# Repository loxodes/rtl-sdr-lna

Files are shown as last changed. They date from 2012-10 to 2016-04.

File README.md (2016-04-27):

**rtl-sdr-lna**

rtl-sdr-lna is a LNA for the ezcap digital TV USB stick (or other USB tuners).
This is intended to improve the sensitivity of it for use as a cheap SDR.

The amplifier is stable, but the matching could probably be improved.

See the following websites for more information on the rtl-sdr:

http://sdr.osmocom.org/trac/wiki/rtl-sdr

http://www.reddit.com/r/rtlsdr

The board is intended to take the place of the RF connector on the ezcap.  

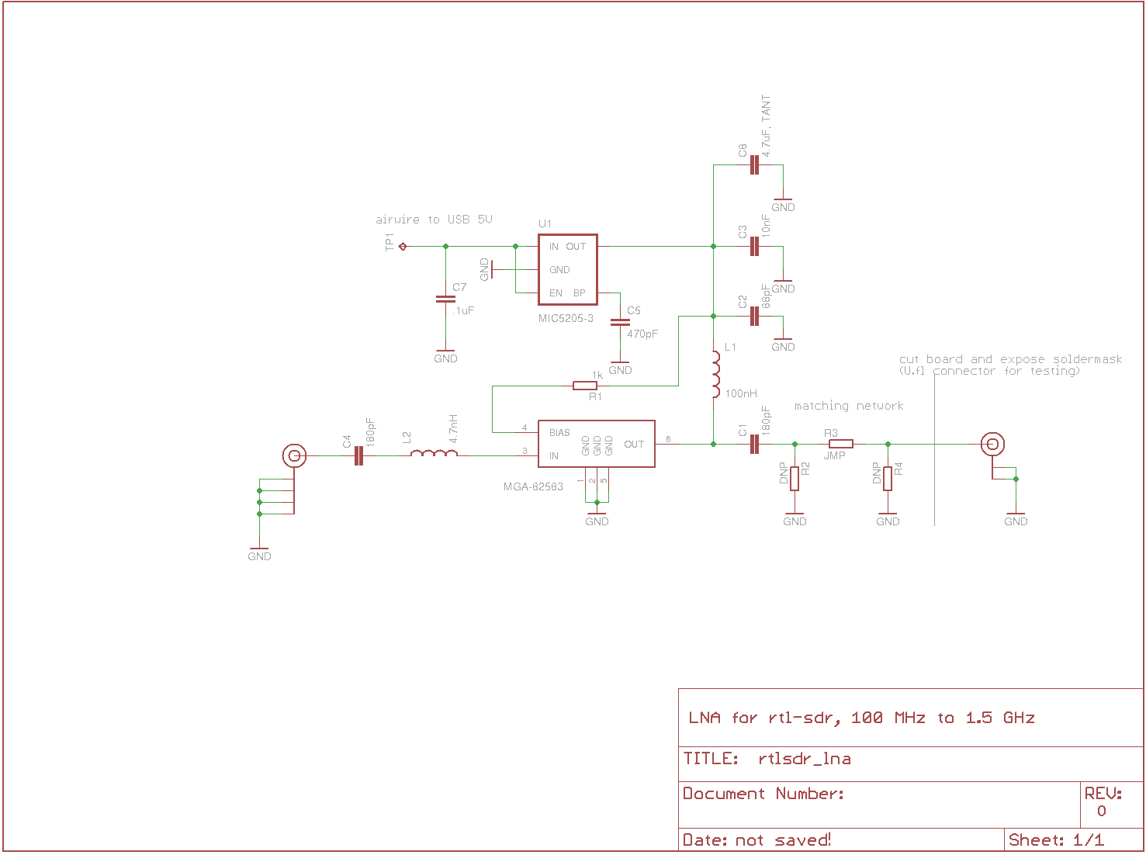
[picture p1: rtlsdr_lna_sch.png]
rtlsdrlna schematic


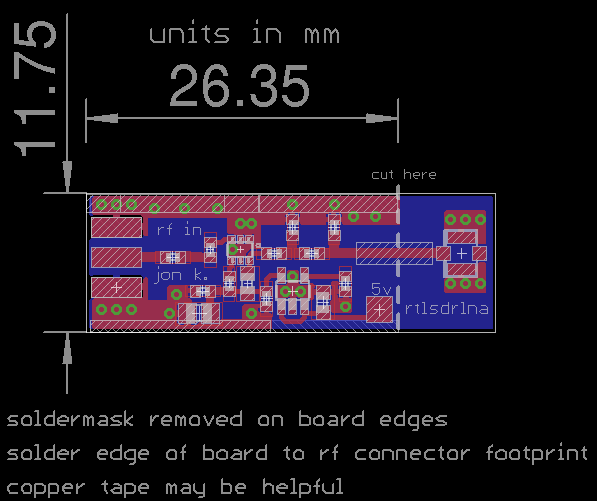
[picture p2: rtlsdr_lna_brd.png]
rtlsdrlna layout


s2p files for simulation are available from Avago and Murata. I'm using ADS for simulation, qucs would be a free open source alternative.

http://www.avagotech.com/pages/en/rf_microwave/amplifiers/low_noise_amplifiers/mga-62563/

http://ds.murata.co.jp/software/simsurfing/en-us/index.html

The PCB can be ordered from OSH Park for $3.15 here: http://oshpark.com/shared_projects/ExVzBewI

All layouts and schematics in this repository are under an MIT license.
Feel free to contact me at jtklein@alaska.edu with suggestions, questions, or complaints.

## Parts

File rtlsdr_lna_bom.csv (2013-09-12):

Qty | Value | Package | Parts
1 | .1uF | C0603 | C7
1 | 100nH | L0603 | L1
1 | 10nF | C0402 | C3
2 | 180pF | C0402 | C1, C4
1 | 1kohm | R0402 | R1
1 | 4.7nH | L0402 | L2
1 | 4.7uF, TANT | C0805 | C6
1 | 470pF | C0402 | C5
1 | 68pF | C0402 | C2
1 | 0 ohm | R0402 | R3
1 | MGA-68563 | SOT363
1 | MIC5205-3 | SOT23-5
1 | SMA_EDGE | SMA-EDGE
1 | U.FL | U.FL

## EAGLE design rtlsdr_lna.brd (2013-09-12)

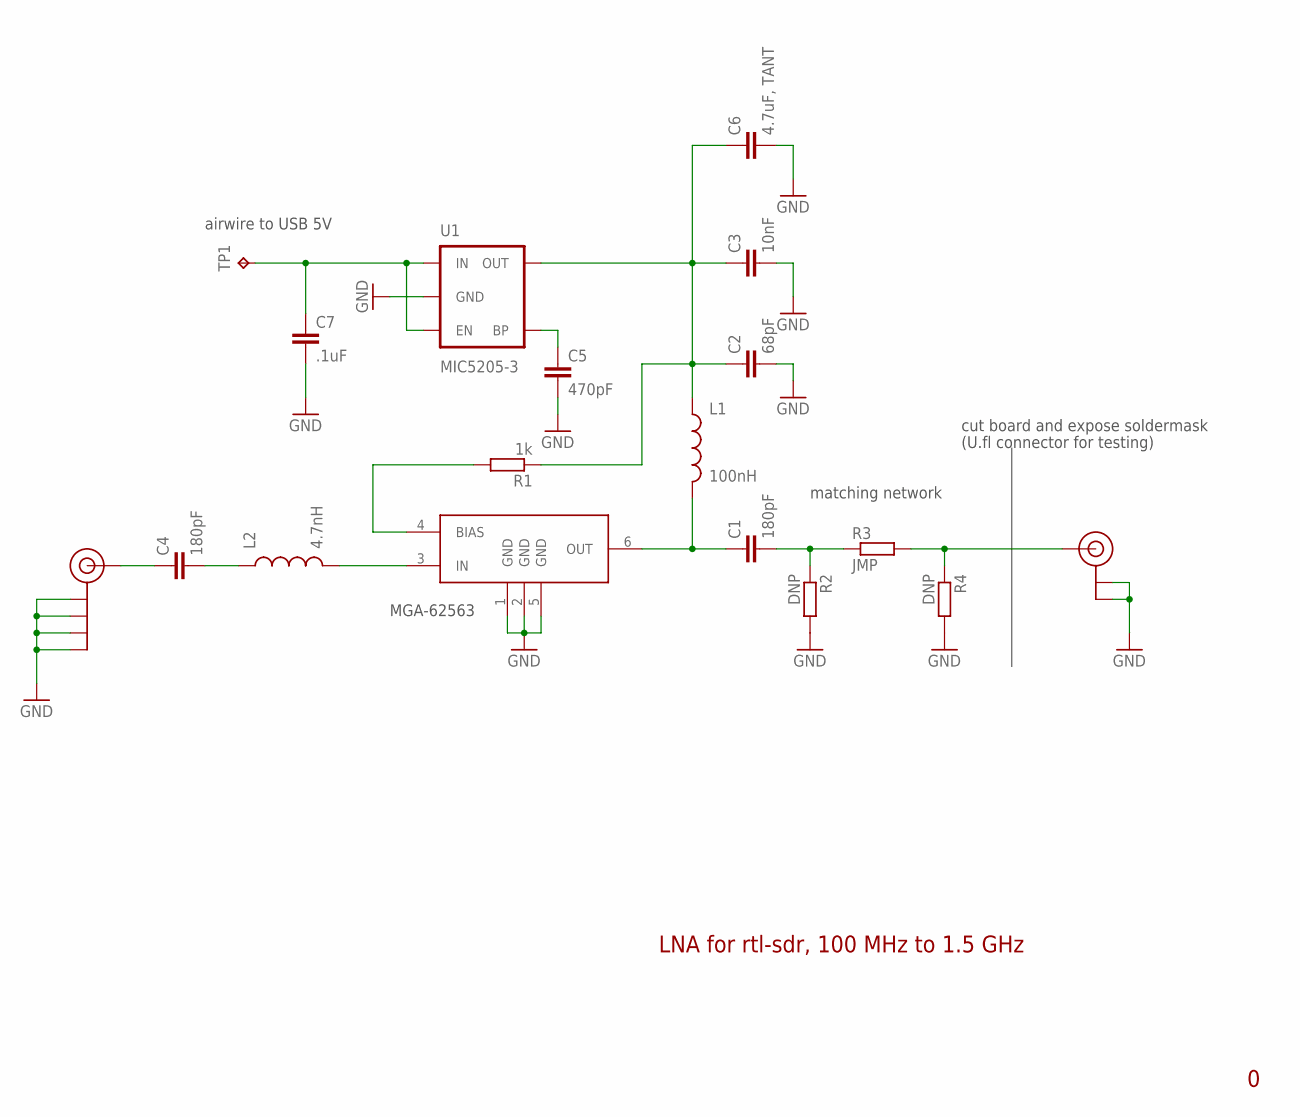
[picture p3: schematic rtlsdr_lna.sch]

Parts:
C1, C4: 180pF; C0402
C2: 68pF; C0402
C3: 10nF; C0402
C5: 470pF; C0402
C6: 4.7uF, TANT; C0805
C7: .1uF; C0603
J$1: SMA_EDGE; SMA-EDGE
L1: 100nH; 0603
L2: 4.7nH; C0402
R1: 1k; R0402
R2, R4: DNP; R0402
R3: JMP; R0402
TP1: TPTP20SQ; TP20SQ
U1: MIC5205-3; SOT23-5
U$1: MGA-68563; SOT363
U$2: U.FL

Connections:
GND: C2.2, C3.2, C5.2, C6.2, C7.2, J$1.GND@0 (GND), J$1.GND@1 (GND), J$1.GND@2 (GND), J$1.GND@3 (GND), R2.2, R4.2, U1.2 (GND), U$1.1 (GND), U$1.2 (GND), U$1.5 (GND), U$2.P$1 (GND), U$2.P$2 (GND)
unnamed: R1.2, U$1.4 (BIAS)
unnamed: C1.2, R2.1, R3.1
unnamed: C1.1, L1.2, U$1.6 (OUT)
unnamed: R3.2, R4.1, U$2.P$3 (SIGNAL)
unnamed: C2.1, C3.1, C6.1, L1.1, R1.1, U1.5 (OUT)
unnamed: C5.1, U1.4 (BP)
unnamed: C7.1, TP1.TP, U1.1 (IN), U1.3 (EN)
unnamed: C4.1, J$1.SIG (SIGNAL)
unnamed: C4.2, L2.1
unnamed: L2.2, U$1.3 (IN)

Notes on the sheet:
matching network
cut board and expose soldermask
(U.fl connector for testing)
airwire to USB 5V
MGA-62563
LNA for rtl-sdr, 100 MHz to 1.5 GHz

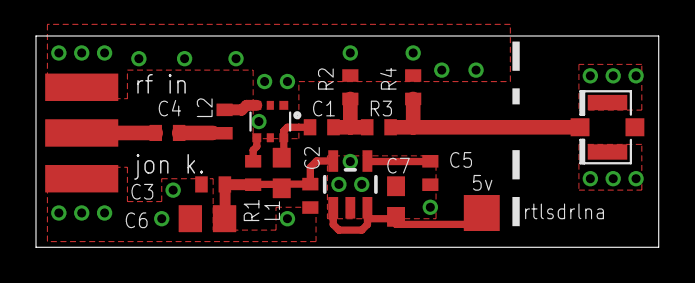
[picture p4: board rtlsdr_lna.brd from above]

Board: 2 copper layers, 34.6 x 11.7 mm, 18 parts (0 on the bottom side), 11 nets.

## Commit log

2012-03-20 initial (untested) commit
    [rtlsdr_lna.brd, rtlsdr_lna.sch]
2012-03-20 increased inductor package size, added missing ldo and rbias component values
    [rtlsdr_lna.brd, rtlsdr_lna.sch]
2012-03-21 changed values in matching network for improved S11 at lower frequencies (increased DC bias inductor value, increased DC blocking capacitor values to 330pF)
    [rtlsdr_lna.brd, rtlsdr_lna.sch]
2012-03-21 reduced board size, increased clearances, changed voltage regulator footprint, added silkscreen and annotations
    [rtlsdr_lna.brd, rtlsdr_lna.sch]
2012-03-21 this time with the new layout and schematic..
    [rtlsdr_lna.brd, rtlsdr_lna.sch]
2012-03-22 cleaned up layout to pass DRC, rtl-sdr-lna ready for manufacturing
    [rtlsdr_lna.brd, rtlsdr_lna.sch]
2012-10-19 moved images of board and schematic to github (fixed broken links to images in the README file)
2013-09-12 cleaned up silkscreen layer, added bom, added link of where to order the pcbs
    [rtlsdr_lna.brd, rtlsdr_lna_bom.csv]

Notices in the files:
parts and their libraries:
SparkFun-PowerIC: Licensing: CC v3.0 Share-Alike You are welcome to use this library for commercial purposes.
